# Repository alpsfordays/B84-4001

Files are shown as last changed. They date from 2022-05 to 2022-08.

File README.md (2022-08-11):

# B84-4001

The B84-4001 keyboard PCB is a replacement (rejuvenation? revival?) PCB that makes use of the G84-4001's layout, switches, and keycaps and puts them into a subjectively more usable form. It was originally created as a personal project to make use of a new-old-stock controller-less G84 module (a G84-4001QAU/00).

It supports one layout, the 83-key layout used by the aforementioned modules, though support for G84 variants with Windows keys may be added in future. No promises. It's all autorouted too, which may change as I work on this more.

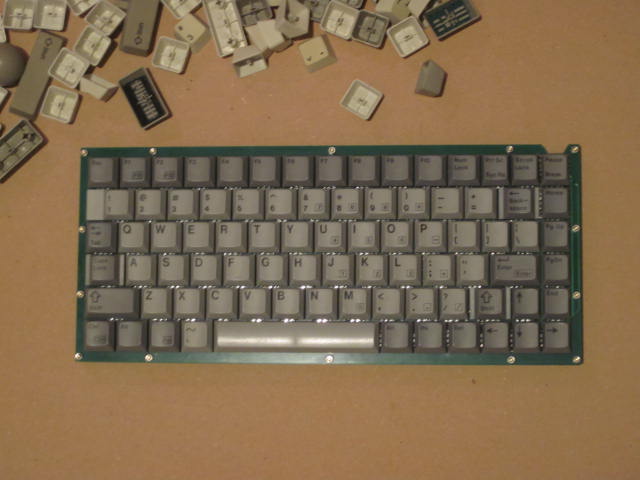
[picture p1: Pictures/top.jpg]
top

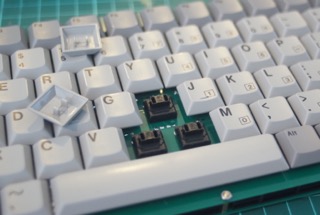
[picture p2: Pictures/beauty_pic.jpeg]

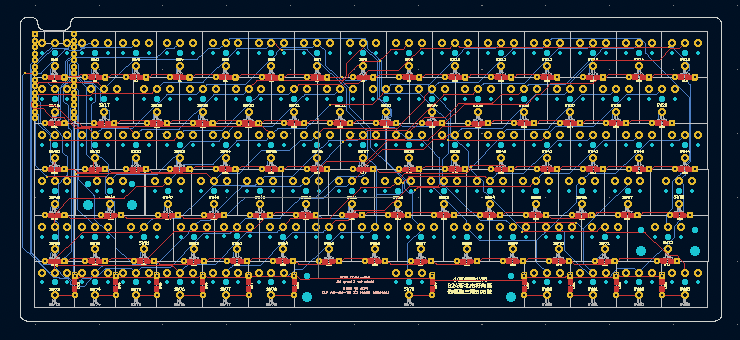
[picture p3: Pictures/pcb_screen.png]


I will gladly assist or give tips on assembly, firmware or use (you can find me on Discord as `bean#7178`), but please first read this README through.

This board is designed for Cherry ML switches in 18mm spacing, mounted directly onto the PCB; ML does not use a plate to hold the switches. The PCB has M2 mount holes along the perimeter, allowing one to make it into a sandwich case with another PCB as the backplate or mount into a custom case. This is **will not fit** in Cherry G84 keyboard cases - it is meant as a standalone keyboard.

I ordered revision zero with green soldermask, 0.8 millimetre with HASL. Revision one (what this repo is) has had its edges tidied up and excess silkscreen reference markings removed. When ordering, I highly recommend *not* specifying 0.8mm thickness - the stock PCB is 1.6mm so I recommend that.

### Controller and Firmware

This board uses an [RP2040 ItsyBitsy](https://www.adafruit.com/product/4888) from Adafruit as the keyboard controller, and the firmware is written in [KMK](https://github.com/KMKfw/kmk_firmware). It should be compatible with any other ItsyBitsy, including the 32u4 variant, but I've yet to try any of those and there may be some tweaks to KMK needed to support them (and of course for the 32u4, a port to TMK/QMK).

### Assembly

Here's the order of operations.

1.  Assemble your parts.
	* 83 Cherry ML switches
	* 83 1N4148 diodes, through-hole or SMD
	* 2.56mm headers
	* An RP2040 ItsyBitsy
	* Keycaps
	* Stabilizer inserts
	* (for sandwich casing) M2\*8 standoffs and M2\*3 screws, rubber feet and a second PCB

2.  Solder the diodes
	* Cathode to the square pads.
	* You will notice there are two sides to the PCB, a side **with** silkscreen and a side without. The side **with** silkscreen is the side from which you will insert or place the diodes - although the pads are also on the other, silkscreen-less side, do not put the diodes on that side unless you wish to have your keycaps bottom out 2 millimetres early.
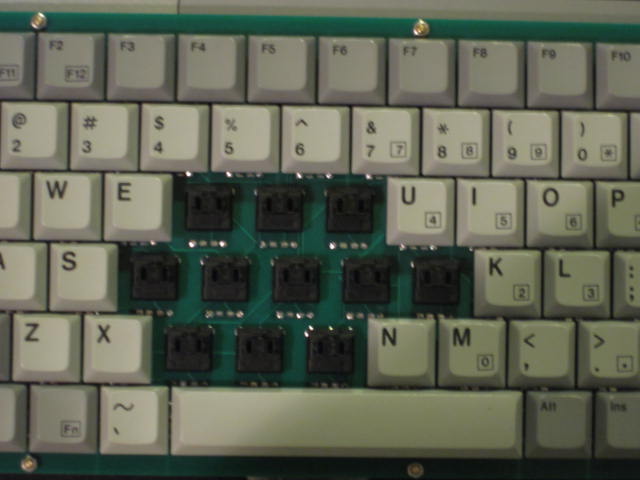
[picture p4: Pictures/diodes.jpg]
	* 
	* Once the diodes are soldered, use a pair of flush-cutters to clip the diode legs as close to the PCB as possible, again because of keycap clearance. Note in the image above that when viewing the PCB from the silkscreen-less side; there should be no diodes visible and the legs should be cut flush or as close to flush as possible. 

3.  Solder the headers.
	* Solder the headers, again on the silkscreen side. Clip the headers to be flush or as close to flush as possible on the silkscreen-less side.

4.  Solder the adorably small switches.
	* Now take your ML switches and solder them in - insert them from the silkscreen-less side and get to work melting metal onto those pins. 

5.  Solder the ItsyBitsy.
	* Test that KMK works on the ItsyBitsy, then solder it in as well, component-side facing away from the PCB.

> For sandwich casing, install the standoffs and screw it all together using the second PCB as a backplate. Install rubber feet as desired.

6.  Test and use.
	* Make sure the keys work correctly and all register. Customize the firmware to suit your needs, though of course note that the matrix's representation in the firmware is reversed because... things (I'm lazy). That it works is what matters to me.
	* Install the stabilizer inserts and keycaps (and a touch of lube on the stabilizer wires to taste).

### Licenses

All software in this repository is licensed under the [GNU Public License,
version 3](https://www.gnu.org/licenses/gpl-3.0-standalone.html).
All hardware designs and documentation is licensed under the [Creative Commons
Attribution-NonCommercial-ShareAlike 4.0](https://creativecommons.org/licenses/by-nc-sa/4.0/)
license.

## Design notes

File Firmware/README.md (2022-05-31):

### How to use this firmware

Install KMK onto the ItsyBitsy and put the code.py into the root directory. Edit and save it as you please. If you want to disable USB drive function in Circuitpython, edit boot.py by adding this code: 
```python
import storage
storage.disable_usb_drive()
```
Save, and then press the reset button or replug the device. The controller will no longer show up as a mass storage device but will still be accessible via the REPL.

To undo this i.e. to re-enable the drive, plug the board in and double-tap the ItsyBitsy's reset button slowly to enter safe mode. The drive should show up and you can edit boot.py to remove the function; however, it will not run any code even after you've saved boot.py or code.py like normal behaviour. You need to press the reset button or replug the device to jump out of safe mode.

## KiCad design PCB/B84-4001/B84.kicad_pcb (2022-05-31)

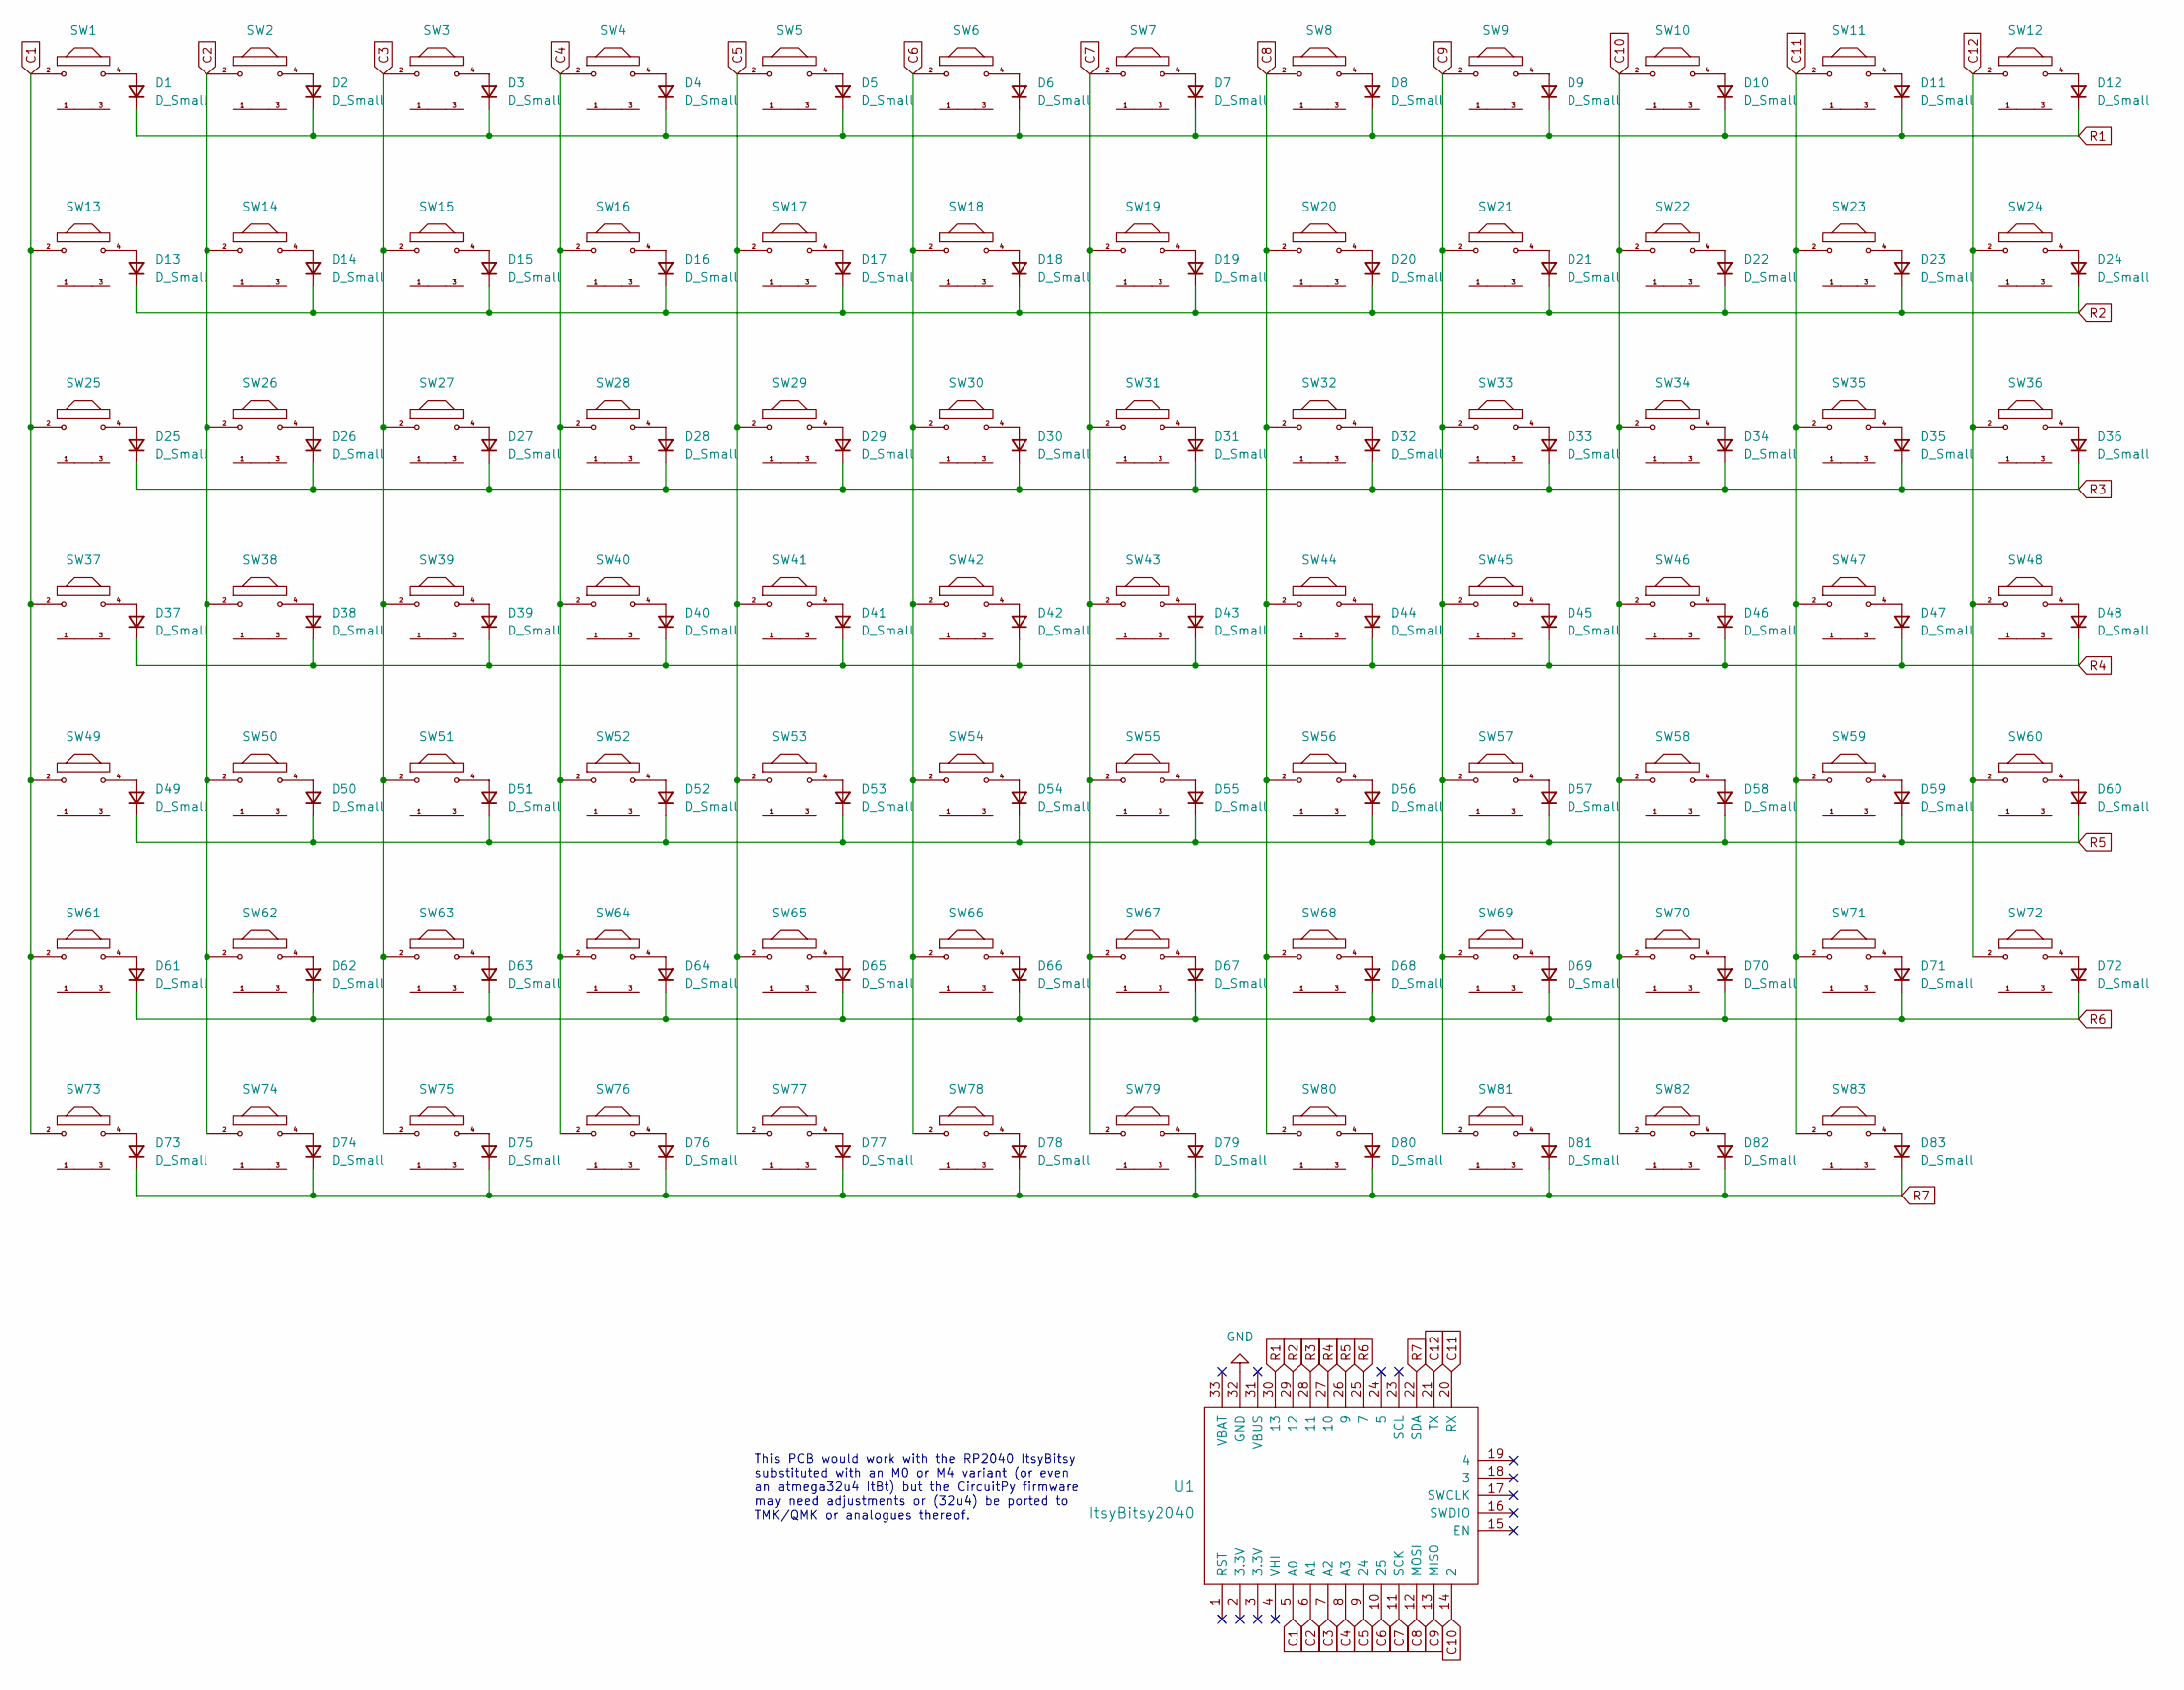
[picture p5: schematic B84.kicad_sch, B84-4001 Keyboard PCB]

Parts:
D1, D2, D3, D4, D5, D6, D7, D8, D9, D10, D11, D12, D13, D14, D15, D16, D17, D18, D19, D20, D21, D22, D23, D24, D25, D26, D27, D28, D29, D30, D31, D32, D33, D34, D35, D36, D37, D38, D39, D40, D41, D42, D43, D44, D45, D46, D47, D48, D49, D50, D51, D52, D53, D54, D55, D56, D57, D58, D59, D60, D61, D62, D63, D64, D65, D66, D67, D68, D69, D70, D71, D72, D73, D74, D75, D76, D77, D78, D79, D80, D81, D82, D83: D_Small
SW1, SW2, SW3, SW4, SW5, SW6, SW7, SW8, SW9, SW10, SW11, SW12, SW13, SW14, SW15, SW16, SW17, SW18, SW19, SW20, SW21, SW22, SW23, SW24, SW25, SW26, SW27, SW28, SW29, SW30, SW31, SW32, SW33, SW34, SW35, SW36, SW37, SW38, SW39, SW40, SW41, SW42, SW43, SW44, SW45, SW46, SW47, SW48, SW49, SW50, SW51, SW52, SW53, SW54, SW55, SW56, SW57, SW58, SW59, SW60, SW61, SW62, SW63, SW64, SW65, SW66, SW67, SW68, SW69, SW70, SW71, SW72, SW73, SW74, SW75, SW76, SW77, SW78, SW79, SW80, SW81, SW82, SW83: ML
U1: ItsyBitsy2040; ibrp2040_custom

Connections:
C1: SW1.2, SW13.2, SW25.2, SW37.2, SW49.2, SW61.2, SW73.2, U1.5 (A0)
C2: SW2.2, SW14.2, SW26.2, SW38.2, SW50.2, SW62.2, SW74.2, U1.6 (A1)
C3: SW3.2, SW15.2, SW27.2, SW39.2, SW51.2, SW63.2, SW75.2, U1.7 (A2)
C4: SW4.2, SW16.2, SW28.2, SW40.2, SW52.2, SW64.2, SW76.2, U1.8 (A3)
C5: SW5.2, SW17.2, SW29.2, SW41.2, SW53.2, SW65.2, SW77.2, U1.9 (24)
C6: SW6.2, SW18.2, SW30.2, SW42.2, SW54.2, SW66.2, SW78.2, U1.10 (25)
C7: SW7.2, SW19.2, SW31.2, SW43.2, SW55.2, SW67.2, SW79.2, U1.11 (SCK)
C8: SW8.2, SW20.2, SW32.2, SW44.2, SW56.2, SW68.2, SW80.2, U1.12 (MOSI)
C9: SW9.2, SW21.2, SW33.2, SW45.2, SW57.2, SW69.2, SW81.2, U1.13 (MISO)
C10: SW10.2, SW22.2, SW34.2, SW46.2, SW58.2, SW70.2, SW82.2, U1.14 (2)
C11: SW11.2, SW23.2, SW35.2, SW47.2, SW59.2, SW71.2, SW83.2, U1.20 (RX)
C12: SW12.2, SW24.2, SW36.2, SW48.2, SW60.2, SW72.2, U1.21 (TX)
GND: U1.32 (GND)
unnamed: D1.2 (A), SW1.4
unnamed: D2.2 (A), SW2.4
unnamed: D3.2 (A), SW3.4
unnamed: D4.2 (A), SW4.4
unnamed: D5.2 (A), SW5.4
unnamed: D6.2 (A), SW6.4
unnamed: D7.2 (A), SW7.4
unnamed: D8.2 (A), SW8.4
unnamed: D9.2 (A), SW9.4
unnamed: D10.2 (A), SW10.4
unnamed: D11.2 (A), SW11.4
unnamed: D12.2 (A), SW12.4
unnamed: D13.2 (A), SW13.4
unnamed: D14.2 (A), SW14.4
unnamed: D15.2 (A), SW15.4
unnamed: D16.2 (A), SW16.4
unnamed: D17.2 (A), SW17.4
unnamed: D18.2 (A), SW18.4
unnamed: D19.2 (A), SW19.4
unnamed: D20.2 (A), SW20.4
unnamed: D21.2 (A), SW21.4
unnamed: D22.2 (A), SW22.4
unnamed: D23.2 (A), SW23.4
unnamed: D24.2 (A), SW24.4
unnamed: D25.2 (A), SW25.4
unnamed: D26.2 (A), SW26.4
unnamed: D27.2 (A), SW27.4
unnamed: D28.2 (A), SW28.4
unnamed: D29.2 (A), SW29.4
unnamed: D30.2 (A), SW30.4
unnamed: D31.2 (A), SW31.4
unnamed: D32.2 (A), SW32.4
unnamed: D33.2 (A), SW33.4
unnamed: D34.2 (A), SW34.4
unnamed: D35.2 (A), SW35.4
unnamed: D36.2 (A), SW36.4
unnamed: D37.2 (A), SW37.4
unnamed: D38.2 (A), SW38.4
unnamed: D39.2 (A), SW39.4
unnamed: D40.2 (A), SW40.4
unnamed: D41.2 (A), SW41.4
unnamed: D42.2 (A), SW42.4
unnamed: D43.2 (A), SW43.4
unnamed: D44.2 (A), SW44.4
unnamed: D45.2 (A), SW45.4
unnamed: D46.2 (A), SW46.4
unnamed: D47.2 (A), SW47.4
unnamed: D48.2 (A), SW48.4
unnamed: D49.2 (A), SW49.4
unnamed: D50.2 (A), SW50.4
unnamed: D51.2 (A), SW51.4
unnamed: D52.2 (A), SW52.4
unnamed: D53.2 (A), SW53.4
unnamed: D54.2 (A), SW54.4
unnamed: D55.2 (A), SW55.4
unnamed: D56.2 (A), SW56.4
unnamed: D57.2 (A), SW57.4
unnamed: D58.2 (A), SW58.4
unnamed: D59.2 (A), SW59.4
unnamed: D60.2 (A), SW60.4
unnamed: D61.2 (A), SW61.4
unnamed: D62.2 (A), SW62.4
unnamed: D63.2 (A), SW63.4
unnamed: D64.2 (A), SW64.4
unnamed: D65.2 (A), SW65.4
unnamed: D66.2 (A), SW66.4
unnamed: D67.2 (A), SW67.4
unnamed: D68.2 (A), SW68.4
unnamed: D69.2 (A), SW69.4
unnamed: D70.2 (A), SW70.4
unnamed: D71.2 (A), SW71.4
unnamed: D72.2 (A), SW72.4
unnamed: D73.2 (A), SW73.4
unnamed: D74.2 (A), SW74.4
unnamed: D75.2 (A), SW75.4
unnamed: D76.2 (A), SW76.4
unnamed: D77.2 (A), SW77.4
unnamed: D78.2 (A), SW78.4
unnamed: D79.2 (A), SW79.4
unnamed: D80.2 (A), SW80.4
unnamed: D81.2 (A), SW81.4
unnamed: D82.2 (A), SW82.4
unnamed: D83.2 (A), SW83.4
R1: D1.1 (K), D2.1 (K), D3.1 (K), D4.1 (K), D5.1 (K), D6.1 (K), D7.1 (K), D8.1 (K), D9.1 (K), D10.1 (K), D11.1 (K), D12.1 (K), U1.30 (13)
R2: D13.1 (K), D14.1 (K), D15.1 (K), D16.1 (K), D17.1 (K), D18.1 (K), D19.1 (K), D20.1 (K), D21.1 (K), D22.1 (K), D23.1 (K), D24.1 (K), U1.29 (12)
R3: D25.1 (K), D26.1 (K), D27.1 (K), D28.1 (K), D29.1 (K), D30.1 (K), D31.1 (K), D32.1 (K), D33.1 (K), D34.1 (K), D35.1 (K), D36.1 (K), U1.28 (11)
R4: D37.1 (K), D38.1 (K), D39.1 (K), D40.1 (K), D41.1 (K), D42.1 (K), D43.1 (K), D44.1 (K), D45.1 (K), D46.1 (K), D47.1 (K), D48.1 (K), U1.27 (10)
R5: D49.1 (K), D50.1 (K), D51.1 (K), D52.1 (K), D53.1 (K), D54.1 (K), D55.1 (K), D56.1 (K), D57.1 (K), D58.1 (K), D59.1 (K), D60.1 (K), U1.26 (9)
R6: D61.1 (K), D62.1 (K), D63.1 (K), D64.1 (K), D65.1 (K), D66.1 (K), D67.1 (K), D68.1 (K), D69.1 (K), D70.1 (K), D71.1 (K), D72.1 (K), U1.25 (7)
R7: D73.1 (K), D74.1 (K), D75.1 (K), D76.1 (K), D77.1 (K), D78.1 (K), D79.1 (K), D80.1 (K), D81.1 (K), D82.1 (K), D83.1 (K), U1.22 (SDA)

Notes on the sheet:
This PCB would work with the RP2040 ItsyBitsy substituted with an M0 or M4 variant (or even an atmega32u4 ItBt) but the CircuitPy firmware may need adjustments or (32u4) be ported to TMK/QMK or analogues thereof.

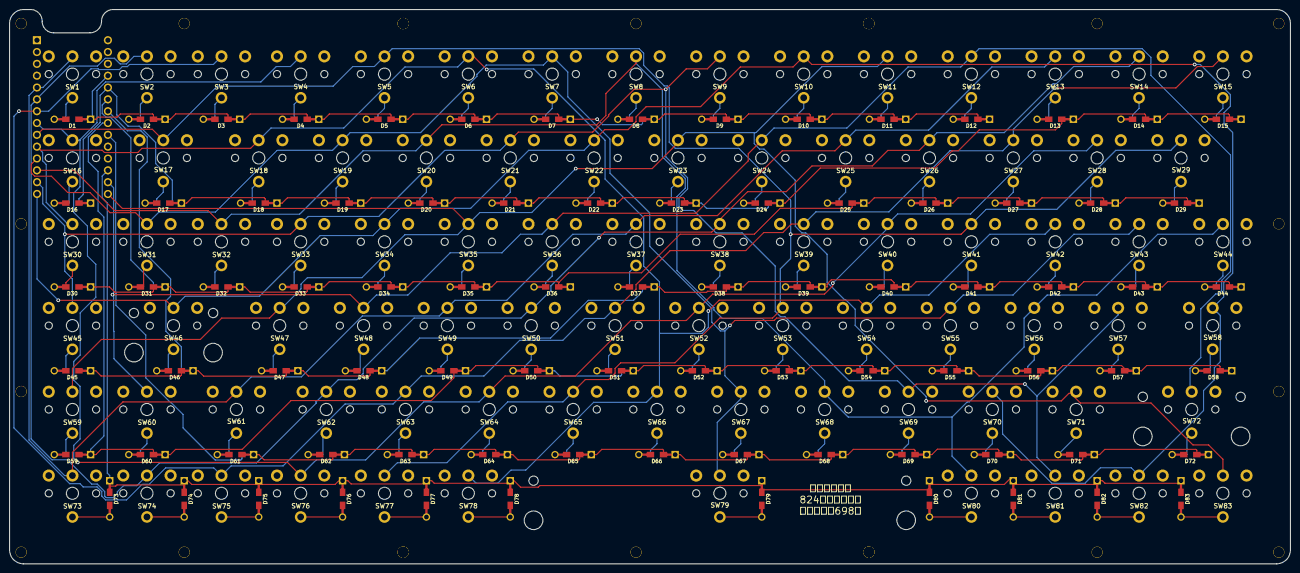
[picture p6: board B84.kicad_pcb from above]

Board: 2 copper layers, 275.0 x 119.0 mm, 185 parts (0 on the bottom side), 102 nets.

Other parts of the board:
J1, J2, J3, J4, J5, J6, J7, J9, J10, J11, J12, J13, J14, J15, J16, J17, J18, J19: D2; SinglePad

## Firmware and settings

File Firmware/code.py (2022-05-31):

import board

from kmk.kmk_keyboard import KMKKeyboard
from kmk.keys import KC
from kmk.modules.layers import Layers
from kmk.modules.modtap import ModTap
from kmk.scanners import DiodeOrientation

keyboard = KMKKeyboard()

modtap = ModTap()
layers_ext = Layers()
keyboard.modules = [layers_ext, modtap]

keyboard.col_pins = (board.A0,board.A1,board.A2,board.A3,board.D24,board.D25,board.SCK,board.MOSI,board.MISO,board.D2,board.RX,board.TX,)    # try D5 on Feather, keeboar
keyboard.row_pins = (board.D13,board.D12, board.D11,board.D10, board.D9,board.D7,board.SDA,)    # try D6 on Feather, keeboar
keyboard.diode_orientation = DiodeOrientation.COL2ROW

keyboard.keymap = [
    [
    KC.PAUS, KC.SLCK, KC.PSCR, KC.TG(1),KC.F10,  KC.F9,   KC.F8,   KC.F7,   KC.F6,   KC.F5,   KC.F4,   KC.F3,   KC.F2,   KC.F1,   KC.ESC,
    KC.HOME, KC.BSPC, KC.EQL,  KC.MINS, KC.N0,   KC.N9,   KC.N8,   KC.N7,   KC.N6,   KC.N5,   KC.N4,   KC.N3,   KC.N2,   KC.N1,
    KC.PGUP, KC.BSLS, KC.RBRC, KC.LBRC, KC.P,    KC.O,    KC.I,    KC.U,    KC.Y,    KC.T,    KC.R,    KC.E,    KC.W,    KC.Q,    KC.TAB,
    KC.PGDN, KC.ENT,  KC.QUOT, KC.SCLN, KC.L,    KC.K,    KC.J,    KC.H,    KC.G,    KC.F,    KC.D,    KC.S,    KC.A,    KC.CAPS,
    KC.END,  KC.UP,   KC.RSFT, KC.SLSH, KC.DOT,  KC.COMM, KC.M,    KC.N,    KC.B,    KC.V,    KC.C,    KC.X,    KC.Z,    KC.LSFT,
    KC.RGHT, KC.DOWN, KC.LEFT, KC.DEL,  KC.INS,  KC.RALT, KC.SPC,  KC.GRV,  KC.LGUI, KC.LALT, KC.LCTL,
    ],
    [
    KC.NO,   KC.NO,   KC.NO,   KC.TRNS, KC.NO,   KC.NO,   KC.NO,   KC.NO,   KC.NO,   KC.NO,   KC.NO,   KC.NO,   KC.F12,  KC.F11,  KC.ESC,  
    KC.NO,   KC.BSPC, KC.NO,   KC.NO,   KC.PAST, KC.P9,   KC.P8,   KC.P7,   KC.NO,   KC.NO,   KC.NO,   KC.NO,   KC.NO,   KC.NO,  
    KC.NO,   KC.NO,   KC.NO,   KC.NO,   KC.PMNS, KC.P6,   KC.P5,   KC.P4,   KC.NO,   KC.NO,   KC.NO,   KC.NO,   KC.NO,   KC.NO,   KC.NO,  
    KC.NO,   KC.PENT, KC.NO,   KC.PPLS, KC.P3,   KC.P2,   KC.P1,   KC.NO,   KC.NO,   KC.NO,   KC.NO,   KC.NO,   KC.NO,   KC.NO,  
    KC.NO,   KC.NO,   KC.NO,   KC.PSLS, KC.PDOT, KC.NO,   KC.P0,   KC.NO,   KC.NO,   KC.NO,   KC.NO,   KC.NO,   KC.NO,   KC.NO,  
    KC.NO,   KC.NO,   KC.NO,   KC.NO,   KC.NO,   KC.NO,   KC.SPC,  KC.NO,   KC.TRNS, KC.TRNS, KC.TRNS,  
    ]
]


if __name__ == '__main__':
    keyboard.go()

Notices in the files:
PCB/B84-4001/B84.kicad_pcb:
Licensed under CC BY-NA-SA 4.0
